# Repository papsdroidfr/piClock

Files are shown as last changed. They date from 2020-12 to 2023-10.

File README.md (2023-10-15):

# piClock
source projet piClock sur [https://www.papsdroid.fr/post/piclock](https://papsdroidfr.github.io/tutoriels/piclock/)

Horloge lumineuse à l'aide d'un raspberry pi zéro aux commandes d'un anneau de 60 leds RGB et d'un afficheur 7 segments adafruit de grande taille (1,2"). Un bouton "off" permet d’éteindre correctement tout le système, et un autre bouton poussoir "select" permet quand à lui de modifier le style de l'horloge, avec une option d'extinction de l'anneau de leds (extinction automatique de l'anneau à minuit)

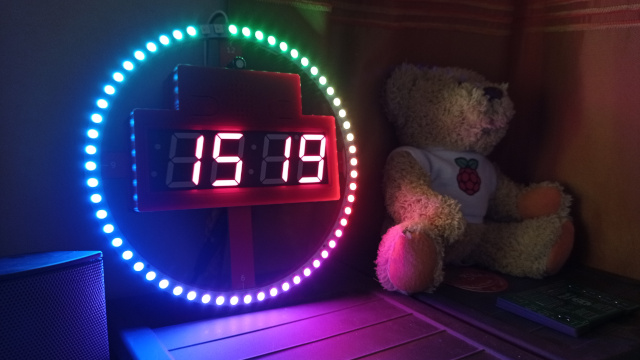
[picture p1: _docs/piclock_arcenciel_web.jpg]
piCLock


## materiel nécessaire

* Un raspberry pi zéro **WH** (wifi et connecteur GPIO): 15 €
* microSD card 16Go sandisk A1  (8Go suffisent): 7€
* Bloc d'alimentation 5V 3A jack: 10€
* Anneau 60 leds RGB 172mm: 30€. Le PCB a été ralisé sur mesure pour [ce modèle](https://www.amazon.fr/gp/product/B07PXDJV48/ref=ppx_yo_dt_b_asin_title_o09_s00?ie=UTF8&psc=1)
* 7 segment-display adafruit 1,2" avec backpack: 25€.  bien prendre [ce modèle 1.2"](https://www.amazon.fr/Adafruit-4-Digit-7-Segment-Display-Backpack/dp/B00XW2NSU2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)
* Carte PCB: comptez 30€ en 5 exemplaires (télécharger les fichiers GERBER zipés sur le github). Il faut simplement commander un PCB double-couche et aucune autre option (laisser les valeurs par défaut proposées): le tarif le moins cher devrait s'appliquer.

divers composants électronique: 5€

* 4 résistances (1/4W) 10kΩ
* 2 boutons poussoir 6mm type NO
* 2 condensateurs céramiques 100nF
* 1 condensateur chimique polarisé 470uF
* 1 barrette 2*20 pin femelle à souder, 2.54mm (pour raspberry pi)
* 1 connecteur jack DC 3 pin à souder
* 1 bornier 3 pins 2.54mm à souder (pour brancher l'anneau)

## Schéma électronique
Ce circuit est facilement réalisable sur une breadboard
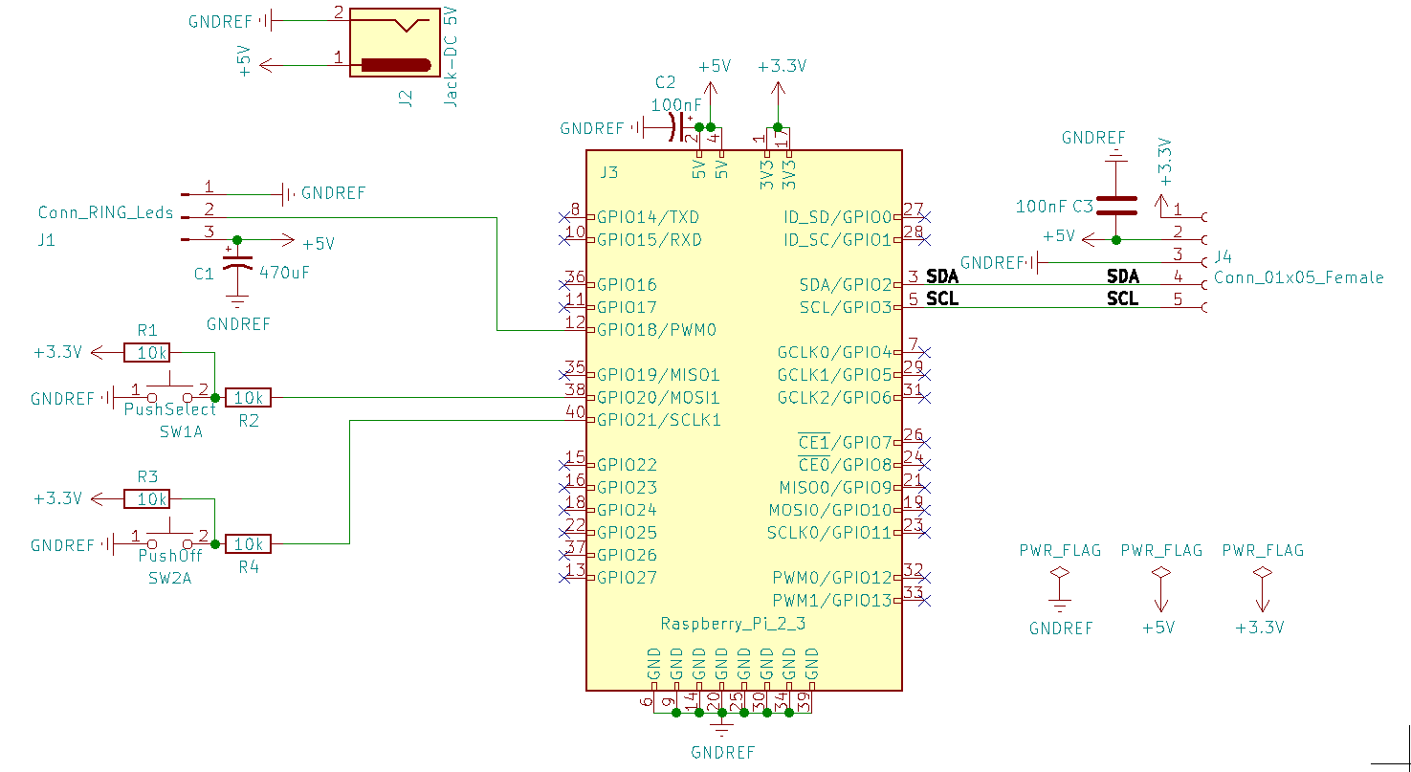
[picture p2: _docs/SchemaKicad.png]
schema


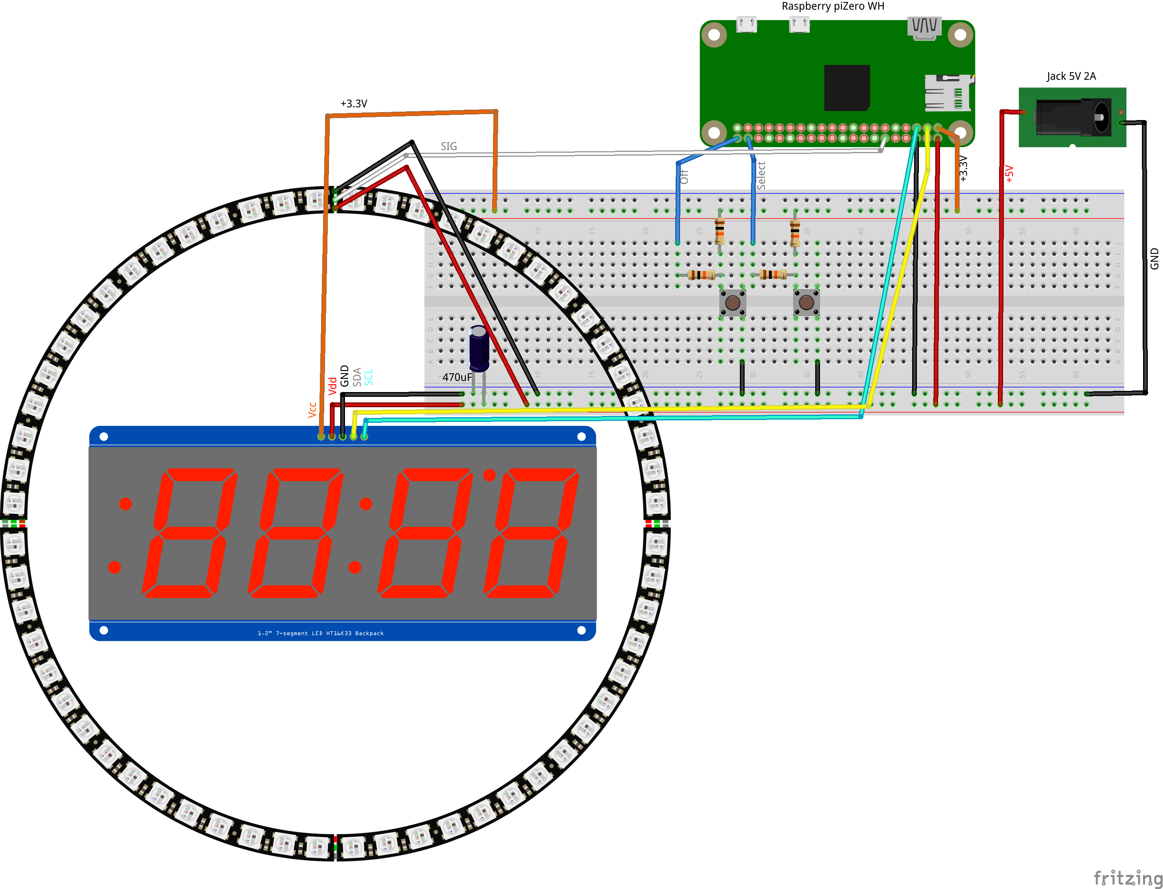
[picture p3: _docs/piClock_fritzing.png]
Fritzing


## configuration du système

Pour configurer son raspberry piZero: suivez [ce guide](https://papsdroidfr.github.io/configuration/config-pzero/)

Installer ensuite les dépendances [Neopixel d'Adafruit](https://learn.adafruit.com/adafruit-neopixel-uberguide/python-circuitpython)

```bach
sudo apt install python3-pip
sudo pip3 install adafruit-circuitpython-neopixel
```

Enfin installer les dépendance [python HT16K33 d'Adafruit](https://learn.adafruit.com/adafruit-led-backpack/python-wiring-and-setup-d74df15e-c55c-487a-acce-a905497ef9db)
qui va permettre de commander l'afficheur 7 segments via son backpack

```bach
pip3 install adafruit-circuitpython-ht16k33
sudo apt-get install python3-pil
```

il reste à récupérer le code Python qui gère toute l'horloge, directement sur mon github,avec ces commandes:

```bach
git clone https://github.com/papsdroidfr/piClock
ls -l
```

Vous devriez voir un répertoire nommé piClock sur /home/pi avec à l’intérieur les fichiers GERBER files zipés (ne servent à rien à ce stade) 
et le programme python **piClock.py**

Dernière étape pour que le programme puisse s’exécuter automatiquement au démarrage du Raspberry pi, ajouter ceci dans le fichier /etc/rc.local:

```bach
sudo nano /etc/rc.local
    # à la fin du fichier, juste avant exit 0 ajouter ceci:
sudo python3 -u '/home/pi/piClock/piClock.py' > '/var/log/piClock.log' 2>&1 &
    # CTRL O pour sauvegarder, puis CTRL-X pour quitter
```

En éteignant le Raspberry pi (sudo poweroff), le programme piClock.py sera automatiquement exécuté à chaque démarrage.

## préparation du circuit

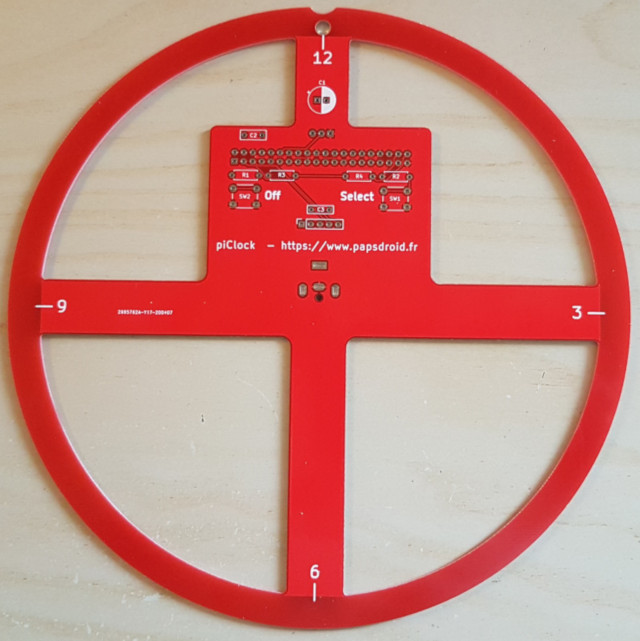
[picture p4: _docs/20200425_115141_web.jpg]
PCB


* Commencer par placer sur le dessus: les 4 résistances, les 2 petits boutons poussoirs et les 2 condensateurs céramiques repérés par c2 et c3 sur le circuit imprimé. Les soudure doivent être réalisée au dessous.
* Souder ensuite le condensateur polarisé c1 (à positionner au dessus comme le reste): attention au sens la patte la plus longue doit être là où est le +
* passons de l'autre côté: au dessous du circuit imprimé pour y placer la barrette femelle 2*20 pin (soudures apparentes au dessus donc), ainsi que le petit bornier 3 points sur lequel on va brancher l'anneau de Leds.
* Reliez au dessous une prise jack DC femelle avec des câbles soudés directement sur les +5V (fil rouge) et GND (fil noir). Les soudures sont donc apparentes au dessus.Pour protéger les courts-circuits il faut mettre un bout de chatterton (rouge) sur les soudures qui risquent de rentrer en contact avec l'électronique du backpack de l'afficheur 7 segment.
* souder ensuite l'afficheur 7 segment directement sur son backpack avec les 5 pin header mâles comme expliqué sur le site d'Adafruit. Attention à ne pas vous tromper de sens ...
* Enfin vous pouvez alors positionner l'afficheur et son backpack et souder les 5 pins dans les 5 trous centraux, juste en dessous du condensateur céramique c3 (attention d'avoir bien soudé d'abord le connecteur jack femelle avant !)

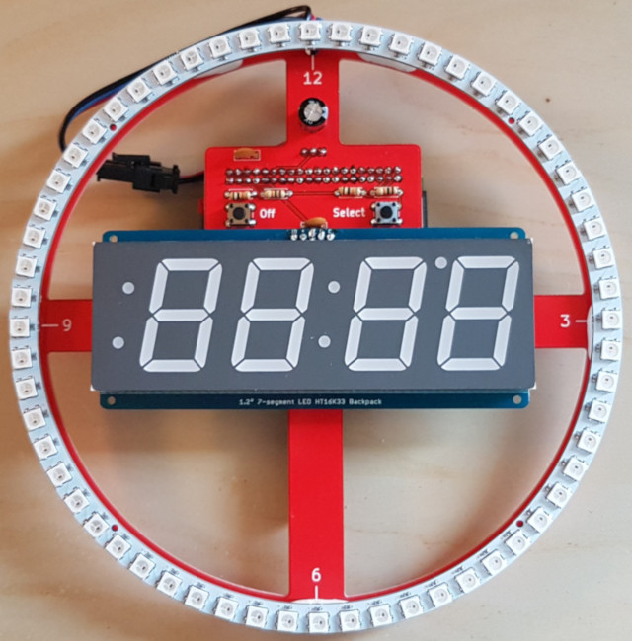
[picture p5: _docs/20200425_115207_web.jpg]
PCB2

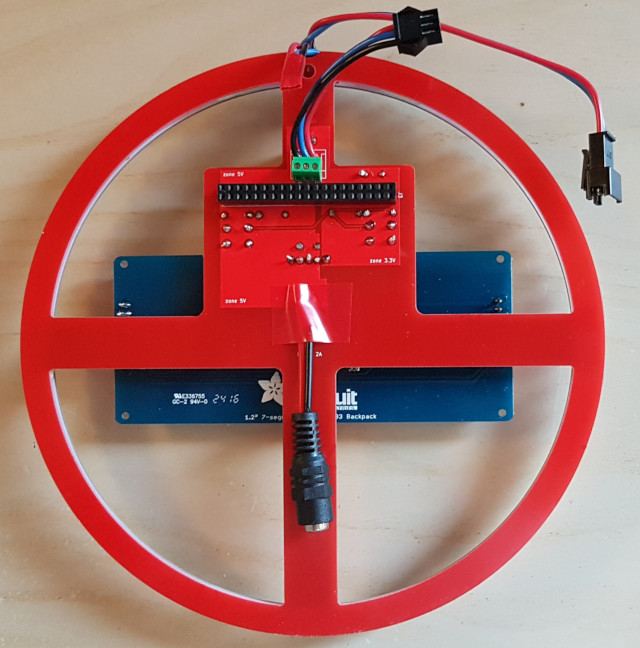
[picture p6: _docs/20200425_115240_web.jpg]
PCB3


* Pour brancher l'anneau j'ai sectionné le cable jst-sm femelle 3 points qui permet de brancher plusieurs anneaux en cascades et l'ai relié au bornier 3 points, afin de pouvoir y brancher l'autre connecteur jst-sm mâle dessus. Vous pouvez aussi tout sectionner pour brancher directement les fils dans le bornier ... Pour protéger les soudures apparentes sur l'anneau j'utilise un petit bout de chatterton rouge.
* Positionnez l'anneau fil vers le haut: la leds 0 doit se trouver au milieu du 12, idem pour les leds 15, 30 et 45 qui doivent être en face du 3, 6 et 9 du circuit imprimé. Pour maintenir l'anneau en place j'utilise des petits morceaux de boule gomme, ce qui permet de gérer l'occupation prises par les fils qui partent de l'anneau.
* Loger ensuite le raspberry pi ZERO sur son connecteur, par dessous donc

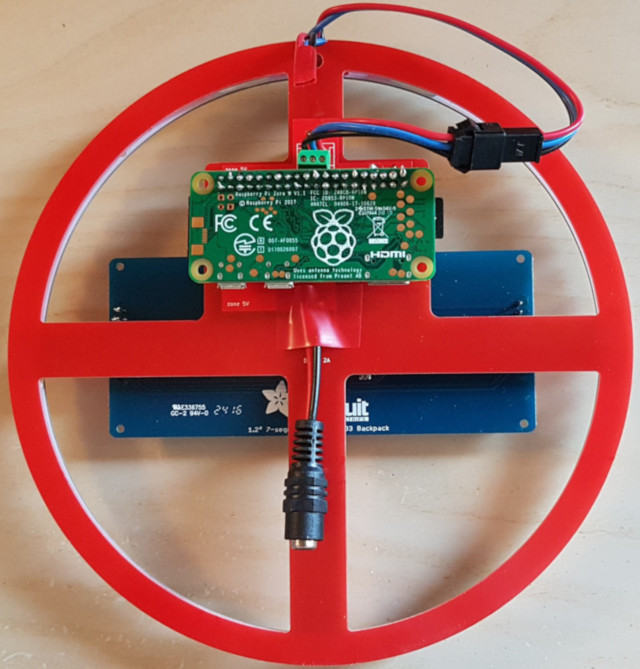
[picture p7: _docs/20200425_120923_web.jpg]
PCB4


Vous pouvez maintenant brancher l'alimentation 5V sur le jack: 
la petite led verte du Raspberry pi zero va clignoter le temps qu'il démarre, et ensuite l'horloge démarre toute seule. 
Il faut laisser le temps au Raspberry pi de se connecter au wifi et l'heure va se mettre à jour toute seule 
C'est normal qu'au premier démarrage l'heure affichée n'est pas immédiatement correcte: dès que le wifi est capté, l'heure va se mettre à jour toute seule.

Plus de détail et vidéo démonstrative sur [papsdroid.fr](https://www.papsdroid.fr/post/piclock)

## boîtier et pied en impression 3D

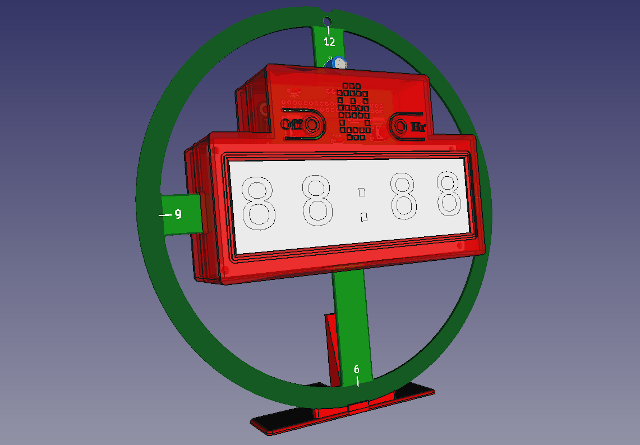
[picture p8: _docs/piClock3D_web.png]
3D


Dans le répertoire /3D_STL il y a les fichiers STL qui permettent d'imprimer en 3D la coque en deux parties (basse et haute) ainsi qu'un pied (optionnel).
Les éléments peuvent tous être imprimés en 0.2mm, les mesures ont été prévues pour.

* coque_basse.stl: partie arrière du boîtier avec un passage pour y loger une vis de fixation à un mur (pied inutile dans ce cas)
* coque_haute.stl: partie qui vient recouvrir le LCD, avec des rehausses de bouton poussoir intégrés.
* pied.stl: il permet de poser l'horloge légèrement inclinée sur une surface plate sans le fixer contre un mur.

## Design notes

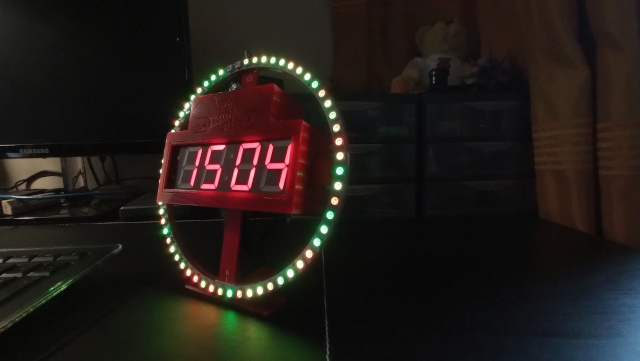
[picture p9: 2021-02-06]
_docs/piclock_green_web.jpg

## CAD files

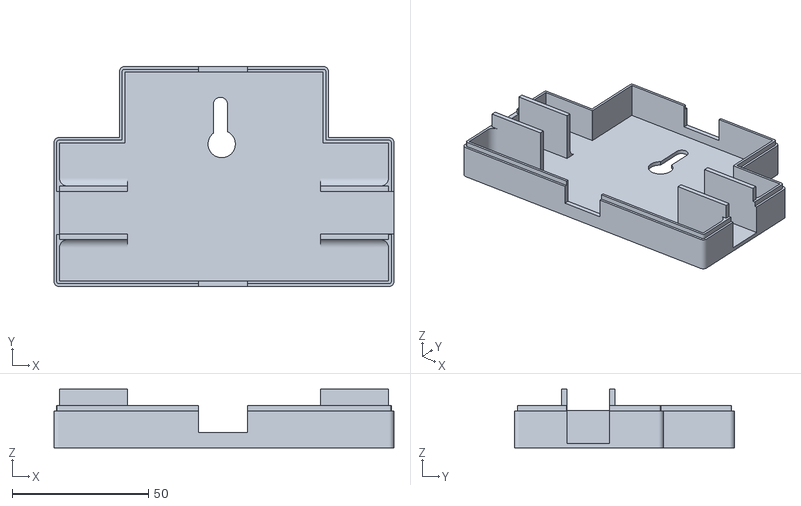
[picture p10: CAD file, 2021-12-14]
3D_STL/coque_basse.stl
124.6 x 80.6 x 21.6

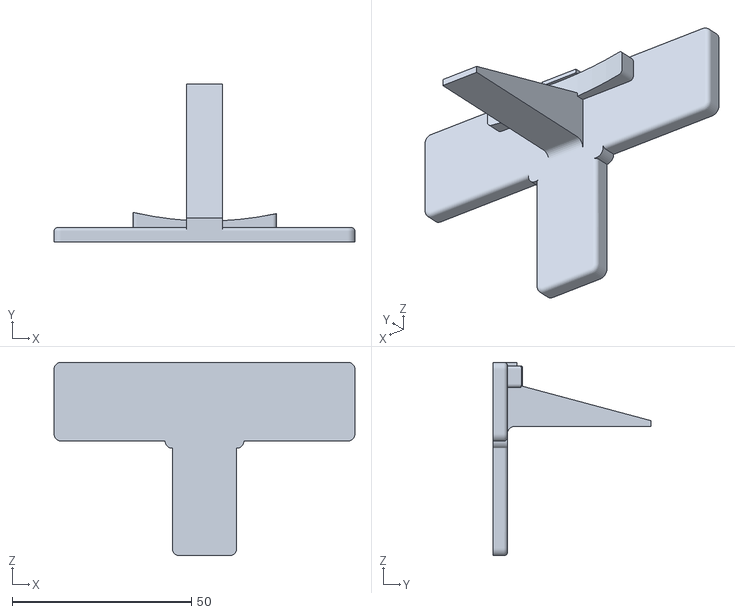
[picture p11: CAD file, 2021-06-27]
3D_STL/pied.stl
84.0 x 44.0 x 54.0

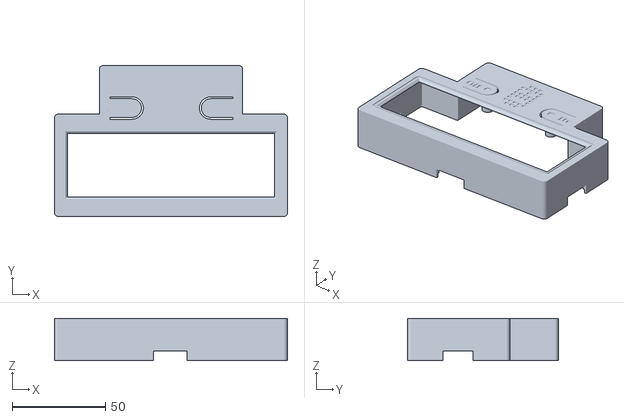
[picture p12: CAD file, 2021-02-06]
3D_STL/coque_haute.stl
124.8 x 80.8 x 22.6

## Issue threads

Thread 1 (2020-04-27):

Pb IO/ERROR avec afficheur 7 segments

papsdroidfr, 2020-04-27:
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

**Fréquence du problème**: rare

**Description**: Il peut arriver un pb IO/ERROR avec l'afficheur 7 segments (package HT16k33), arrêtant brutalement le thread Timer ce qui fige l'horloge. (voir screenshot)

**Solution à envisager**:  Il faut encapsuler les mises à jour de l'afficheur 7 segments avec une gestion d'exception. Si pb persistants provoquer un reboot dans ce cas.

Closed 2020-04-29.

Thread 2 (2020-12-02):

Schema et paramètres JLCPCB

pgille, 2020-12-02:
Bonjour,

Merci pour ce projet
Vous serait-il possible d'ajouter :
- un schéma technique pour présenter le montage ? cela permettra de tester avant le montage
- des photos de votre montage (éléments électroniques soudés)
- les paramètres à saisir sur le site JLBPCB pour commander

Merci beaucoup
cordialement

papsdroidfr, 2020-12-02:
Bonsoir, merci. J'ai documenté directement le readme du Github avec les photos que j'ai prises à l'époque et les explications pour faire les soudures. Je mis à jour l'export Gerber avec un connecteur Jack beaucoup plus facile à trouver que celui que j'ai initialement imaginé: il s'agit d'un jack 3 points, c'est très standard. Au début je pensais prendre un barrel-jack 4 points mais c'est une vrai galère à trouver.

Côté soudure il n'y a vraiment aucun piège, juste penser à bien respecter le sens de la capacité.

Je vais bientôt faire un update pour proposer l'impression d'un boitier imprimé 3D, vu que je viens tout juste d’acquérir une imprimante 3D. Ca permettra de planquer les soudures et de rajouter une accroche pour la positionner sur un mur.

pgille, 2020-12-03:
Bonjour,
Merci pour votre réponse.
Je souhaiterais commander la carte PCB mais je ne suis pas encore habitué à ce type de commande.
Il est demandé des paramètres pour le devis et la configuration : pourriez-vous les préciser svp pour que je puisse être sûr de commander une carte avec les bonnes préconisations (taille épaisseur, type de carte etc) ?
Par avance, merci beaucoup

papsdroidfr, 2020-12-03:
En journée je fais un screenshots de jlcpcb. Mais c'est vraiment super simple car il faut laisser tous les paramètres par défaut proposés par jlcpcb sans rien toucher. Cliquer sur le premier choix  2 layers, uploader le gerber zippé, et tous les paramètres proposés par défaut ne doivent pas être modifié: il n'y a rien de particulier à faire de plus que ça.

pgille, 2020-12-03:
Rebonjour,
C'est une première pour moi, d'où ma sollicitation : en faisant une première fois grâce à vos infos, cela me permettra de me former et de pouvoir refaire par la suite.
Cela me permettra de faire une première commande réussie en étant sûr que je suis sur les bons rails sur ce projet.
Merci encore pour vos réponses et vos projets que je vais suivre.
Mon 1er objectif est de créer cette piclock pour ma fille de 12 ans : cela faisait un moment que je papillonnais en cherchant le bon site avec les bonnes infos : du coup, j'ai déjà commandé des éléments hier soir et il me reste surtout cette carte PCB !
merci

Closed 2020-12-02.

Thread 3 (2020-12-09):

câblage montage soudure

pgille, 2020-12-09:
Bonjour,
Je vais sans aucun doute poser quelques questions stupides..., je m'en excuse par avance.

Je ne vois pas bien sur les photos dans le fichier readme.md comment / à quoi est connecté le connecteur JST femelle 3 points
Idem concernant le connecteur Jack femelle
Par ailleurs, quand vous écrivez : souder ensuite l'afficheur 7 segment directement sur son backpack avec les 5 pin header mâles comme expliqué sur le site d'Adafruit. Attention à ne pas vous tromper de sens
Avant de me tromper, je viens de regarder le site, mais quel sens faut -il bien prendre en compte ?
merci pour votre aide
Cordialement

papsdroidfr, 2021-01-18:
le connecteur JST est à connecter aux 3 fils du ruban de leds: il y a un +5V, un GND et un fil SIG : les sérigraphies sur le PCB indiquent le raccordement à faire. Idem pour souder le backpack sur l'afficheur 7 segment Adafruit indique bien les sérigraphies à v&rifier pour s'assurer de ne pas le souder à l'envers.

Closed 2021-01-18.

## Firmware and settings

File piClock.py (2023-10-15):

#!/usr/bin/env python3
# -*- coding: utf-8 -*- 
########################################################################
# Filename    : piClock.py
# Description : horloge numérique
# auther      : papsdroid.fr
# modification: 2020/03/13
########################################################################

import RPi.GPIO as GPIO
import time, threading, os, board, neopixel
from datetime import datetime
from random import randrange
from adafruit_ht16k33.segments import BigSeg7x4

HH_TIME_OFF = '00:00:00'    #Heure d'extinction automatique hh:mn:ss
LEDS_OFF_AUTO = True        #False/True: si True l'anneau de leds s'éteind à HH_TIME_OFF
DISPLAY_OFF_AUTO = True     #False/True: si Ture le display de l'heure s'éteind à HH_TIME_OFF

#-----------------------------------------------------
# classe de gestion d'un anneau de 60 leds Neopixels
#-----------------------------------------------------
class RingLeds():
    def __init__(self, nb_leds):
        self.pixel_pin = board.D18       # GPIO18 envoie les commandes au ruban
        self.nb_leds = nb_leds           # nb de leds du ruban
        self.pixels = neopixel.NeoPixel(self.pixel_pin, self.nb_leds, brightness=0.1, auto_write=False, pixel_order=neopixel.GRB)
        self.hh = datetime.now().strftime('%H')
        self.mn = datetime.now().strftime('%M')
        self.secondes = int(datetime.now().strftime('%S'))  # secondes à afficher
        self.rgbc1 = 0xFF0000          # couleur rouge RGB
        self.rgbc2 = 0x1d0221          # couleur violette RGB
        self.rgbHhigh  = 0xff0000      # couleur pour les heures
        self.rgbHmedium = 0xff4300     # couleur pour les heures 
        self.rgbHlow  = 0xff742c       # couleur pour les heures
        self.rgbM  = 0x008000          # couleur pour les minutes
        self.rgbS  = 0x000080          # couleur pour les secondes 
        self.rgbMIN = 10       	       # minimum pour générer un niveau de  couleur au hasard entre 0 et 255
        self.rgbMAX = 127              # maximum pour générer un niveau de  couleur au hasard entre 0 et 255 
        self.anims_secondes = ['self.ledn_wheel_on()', 'self.ledn_red_on()', 'self.ledn_random_on()','self.ledn_randomB_on()',
                               'self.ledn_randomR_on()','self.ledn_randomG_on()']
        self.anims = ['self.ledn_anim_secondes()', 'self.time()', 'self.pause()']
        self.id_anim=0                   # référence de l'animation leds, incrémentée avec le bouton poussoir
        self.id_pause = 2                # id animation pause
        self.id_anim_secondes = 0        # référence de l'animation leds secondes en cours, modifiée toutes les minutes
        self.change_anim_secondes = False # état du changement d'animation des secondes
        self.actif = True                # True: anneau actif
        self.init = True                 # True: allume toutes les leds de rang <= secondes en cours
                                         # False: allume uniquement la led de rang = secondes en cours
    #mise à jour des secondes et animation anneau de leds
    #----------------------------------------------------
    def set_time(self, hh,mn,ss):
        self.hh, self.mn, self.secondes = hh, mn, ss
        if (self.id_anim < len(self.anims)-2) and (self.secondes == 0) :
            self.led_anim_off()         # animation pour éteindre toutes les leds sur les animations de type secondes
        exec(self.anims[self.id_anim])  # animation correspondante à id_anim

    def ledn_anim_secondes(self):
        exec(self.anims_secondes[self.id_anim_secondes])         # animation correspondant à  id_anim_secondes
        if self.change_anim_secondes and self.secondes == 0:      # changement d'animation toutes les minutes si pas déjà changé
            self.id_anim_secondes_suivant()
            self.change_anim_secondes = False
        if not(self.change_anim_secondes) and self.secondes > 0:
            self.change_anim_secondes = True

    # gestion des animations en boucle
    #-----------------------------------
    def id_anim_suivant(self):
        self.id_anim = (self.id_anim+1) %  len(self.anims)
        if self.id_anim == 0:
            self.actif=True
        self.init = True

    # gestion des animations secondes modifiées toutes les minutes
    # -----------------------------------------------------------
    def id_anim_secondes_suivant(self):
        self.id_anim_secondes = (self.id_anim_secondes + 1) % len(self.anims_secondes)

    #mise en pause du ruban de leds
    #----------------------------------------------
    def pause(self):
        self.actif=False
        self.off()

    #extinction des leds
    #----------------------------------------------
    def off(self):
        self.pixels.fill((0, 0, 0))
        self.pixels.show()

    #détermine les leds à allumer [debut, fin[ en fonction de self.init
    #------------------------------------------------------------------
    def slotLeds(self):
        debut, fin = self.secondes, self.secondes+1
        if self.init:
            debut = 0
            self.init = False
        return debut, fin

    #allume la led de rang n=secondes avec une couleur arc-en-ciel indexée par n
    #------------------------------------------------------------------
    def ledn_wheel_on(self):
        debut, fin = self.slotLeds()
        for l in range(debut, fin):
            pixel_index = (l * 256 // self.nb_leds)
            self.pixels[l] = self.wheel(pixel_index & 255)
        self.pixels.show()

    #allume la led de rang n avec une couleur self.rgbRED
    #----------------------------------------------------
    def ledn_red_on(self):
        debut, fin = self.slotLeds()
        for l in range(debut, fin):
            if (l%2==0):
                self.pixels[l] = self.rgbc1
            else:
                self.pixels[l] = self.rgbc2
        self.pixels.show()

    #allume la led de rang n avec une couleur au hasard
    #--------------------------------------------------
    def ledn_random_on(self):
        debut, fin = self.slotLeds()
        for l in range(debut, fin):
            r,g,b = 0,0,0
            while (r+g+b) <= self.rgbMIN :
                r,g,b = randrange(0,self.rgbMAX), randrange(0,self.rgbMAX), randrange(0, self.rgbMAX)
            self.pixels[l] = [r,g,b]
            #self.pixels[l] = [self.rgbMIN, 0,0]
        self.pixels.show()

    #allume la led de rang n avec une couleur sauf BLEUE au hasard
    #--------------------------------------------------------------
    def ledn_randomB_on(self):
        debut, fin = self.slotLeds()
        for l in range(debut, fin):
            r,g,b = 0,0,0
            while (r+g+b) <= self.rgbMIN :
                r,g,b = randrange(self.rgbMIN,self.rgbMAX), randrange(self.rgbMIN,self.rgbMAX), 0
            self.pixels[l] = [r,g,b]
        self.pixels.show()

    #allume la led de rang n avec une couleur sauf ROUGE  au hasard
    #--------------------------------------------------------------
    def ledn_randomR_on(self):
        debut, fin = self.slotLeds()
        for l in range(debut, fin):
            r,g,b = 0,0,0
            while (r+g+b) <= self.rgbMIN :
                r,g,b = 0, randrange(0,self.rgbMAX), randrange(0,self.rgbMAX)
            self.pixels[l] = [r,g,b]
        self.pixels.show()

    #allume la led de rang n avec une couleur VERTE  au hasard
    #--------------------------------------------------
    def ledn_randomG_on(self):
        debut, fin = self.slotLeds()
        for l in range(debut, fin):
            r,g,b = 0,0,0
            while (r+g+b) <= self.rgbMIN :
                r,g,b = randrange(0, self.rgbMAX), 0, randrange(0, self.rgbMAX)
            self.pixels[l] = [r,g,b]
        self.pixels.show()

    #affiche heure, minutes et secondes sur le cadran
    def time(self):
        rang_hh, rang_mn = int(self.hh)%12, int(self.mn)
        rang_hh = int(self.nb_leds*(rang_hh+rang_mn/60)/12)
        rang_hhP, rang_hhM = (rang_hh-2)%self.nb_leds, (rang_hh-1)%self.nb_leds
        rang_mn = int(self.nb_leds*rang_mn/60)
        self.pixels.fill((0, 0, 0))
        self.pixels[rang_hh] = self.rgbHhigh
        self.pixels[rang_hhP] = self.rgbHlow
        self.pixels[rang_hhM] = self.rgbHmedium
        self.pixels[rang_mn] = self.rgbM
        self.pixels[self.secondes] = self.rgbS
        self.pixels.show()

    #etteint progressivement les leds dans le sens inverse des aiguilles d'une montre
    #--------------------------------------------------------------------------------
    def led_anim_off(self):
        for i in range(self.nb_leds-1,0,-1):
            self.pixels[i] = [0,0,0]
            self.pixels.show()
            time.sleep(0.001)

    # Input a value 0 to 255 to get a color value.
    # The colours are a transition r - g - b - back to r.
    # ----------------------------------------------------
    def wheel(self, pos):
        if pos < 0 or pos > 255:
            r = g = b = 0
        elif pos < 85:
            r = int(pos * 3)
            g = int(255 - pos*3)
            b = 0
        elif pos < 170:
            pos -= 85
            r = int(255 - pos*3)
            g = 0
            b = int(pos*3)
        else:
            pos -= 170
            r = 0
            g = int(pos*3)
            b = int(255 - pos*3)
        return (r, g, b)

#------------------------------------------------------------------
# classe de gestion de l'afficheur 7 segment Adagruit avec backpack
#------------------------------------------------------------------
class SevenDisplay():
    def __init__(self):
        self.i2c = board.I2C()
        self.display = BigSeg7x4(self.i2c)
        self.display.brightness = 0.4
        self.display.blink_rate = 0
        self.hh = "00"     # heure
        self.mn = "00"     # minutes
        self.actif = True  # display actif au démarrage
        self.off()         # étteint l'afficheur 7 segments au démarrage

    #mise à jour de l'heure
    #------------------------------
    def set_time(self, hh, mn, ss, ds):
        colon = False
        if ds <5 :      # dixième de secondes: fait clignoter le séparateur toutes les 1/2 secondes
            colon = True
        try:
            self.display.colon = colon
            self.display.print(hh+mn)
            self.display.show()
        except:
            print('Warning io/error communication 7segment display ', datetime.now())
            #os.system('sudo reboot') #reboot le système


    # extinction de l'afficheur
    #----------------------------------------------
    def off(self):
        self.display.fill(0)
        self.display.show()

#--------------------------------------------------------------------------------------------------
# class Timer(thread): gère l'affichage du temps sur l'anneau de leds et l'afficheur 7 segments
#--------------------------------------------------------------------------------------------------
class Timer(threading.Thread):
    def __init__(self, ringLeds, display):
        threading.Thread.__init__(self)  # appel au constructeur de la classe mère Thread
        self.etat=False               # True: thread démarré
        self.ringLeds = ringLeds         # anneau de leds pour afficher les secondes
        self.display = display           # afficheur 7 segments pour afficher hh et mn
        self.hh = "00"     # heure
        self.mn = "00"     # minutes
        self.ss = 0        # secondes
        self.ds = 0        # dixièmes de secondes
        self.start()       # démarrage du thread

    #maj heure du timer
    #------------------------------
    def set_time(self, hh,mn,ss, ds):
        self.hh, self.mn, self.ss, self.ds = hh, mn,ss , ds

    #extinction du timer
    #-------------------
    def off(self):
        self.display.off()
        self.ringLeds.off()

    #exécution du thread
    #-------------------
    def run(self):
        self.off()
        self.etat = True
        while (self.etat):
            if self.ringLeds.actif:
                self.ringLeds.set_time(self.hh, self.mn, self.ss)
                #self.ringLeds.set_time("12","18",self.ss") # tests
            if self.display.actif:
                self.display.set_time(self.hh, self.mn, self.ss, self.ds)
            time.sleep(0.1)
        self.off()

    #arrêt du thread (ne peut plus redémarrer après)
    #----------------------------------------------
    def stop(self):
        self.etat=False


#classe d'Application principale
#------------------------------------------------------------------------------------------------------
class Application:
    def __init__(self):
        print('démarrage piCLock', datetime.now())
        self.display = SevenDisplay()                # affichage 7 segments
        self.leds = RingLeds(60)                     # rubans de 60 leds
        self.timer = Timer(self.leds, self.display)  # thread timer 
        self.buttonSelectPin = 20       # bouton pour changement d'animation
        self.buttonOffPin = 21          # bouton d'extinction
        #pin associés aux boutons poussoirs
        GPIO.setup(self.buttonSelectPin, GPIO.IN, pull_up_down=GPIO.PUD_UP)     # mode INPUT, pull_up=high
        GPIO.setup(self.buttonOffPin, GPIO.IN, pull_up_down=GPIO.PUD_UP)        # mode INPUT, pull_up=high
        GPIO.add_event_detect(self.buttonSelectPin,GPIO.FALLING,callback = self.buttonSelectEvent, bouncetime=300)
        GPIO.add_event_detect(self.buttonOffPin,GPIO.FALLING,callback=self.buttonOffEvent, bouncetime=300)

    #méthode de destruction
    def destroy(self):
        print ('bye')
        self.timer.stop() # arrêt du thread timer
        time.sleep(1)
        GPIO.cleanup()

    #bouton poussoir SELECT: change l'animation du ruban de leds et actif le display
    #-------------------------------------------------------------------------------
    def buttonSelectEvent(self,channel):
        self.leds.id_anim_suivant()
        self.display.actif = (self.leds.id_anim < 2)
        if not self.display.actif:
            self.display.off()
        #print('Select pressed,','leds:',self.leds.id_anim, 'display:',self.leds.actif, self.display.actif )

    #bouton poussoir OFF: extinction système
    #----------------------------------------
    def buttonOffEvent(self,channel):
        print('Extinction du système')
        self.timer.stop()
        self.timer.off()
        os.system('sudo halt') #provoque l'extinction du Raspberry pi

    #boucle principale du prg
    def loop(self):
        while True:
            now = datetime.now()
            hh = now.strftime('%H')      # heure sur 2 chiffres
            mn = now.strftime('%M')      # minutes sur 2 chiffres
            ss = now.strftime('%S')      # secondes converties en entier
            ds = now.strftime('%f')[0]   # 1er unités des microsecondes sur 6 chiffres (1/10 secondes)
            #print('time:', hh,mn,ss, ds)
            self.timer.set_time(hh,mn,int(ss),int(ds))
            # mise en pause automatique à HH_TIME_OFF:00:00
            if hh+":"+mn+":"+ss == HH_TIME_OFF:
                if LEDS_OFF_AUTO and self.timer.ringLeds.actif:
                    self.timer.ringLeds.id_anim = self.timer.ringLeds.id_pause
                if DISPLAY_OFF_AUTO and self.display.actif:
                    self.display.actif = False
                    self.display.off()
            time.sleep(0.1)

if __name__ == '__main__':
    appl=Application() 
    try:
        appl.loop()
    except KeyboardInterrupt:  # interruption clavier CTRL-C: appel à la méthode destroy() de appl.
        appl.destroy()
    except KeyboardInterrupt:  # interruption clavier CTRL-C: appel à la méthode destroy() de appl.
        appl.destroy()
